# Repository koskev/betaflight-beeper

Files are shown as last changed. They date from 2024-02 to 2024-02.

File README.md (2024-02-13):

# bf-beeper

This is a small beeper board, which is designed to find a lost model aircraft.
It functions pretty much identical to the other commercial beepers.
The main feature is the ability to deactivate the beeper using Betaflight.

Just activate the normal beeper function of Betaflight and pull the battery.
Since the manual beep pattern is unique all other beep sources won't trigger the disarm.

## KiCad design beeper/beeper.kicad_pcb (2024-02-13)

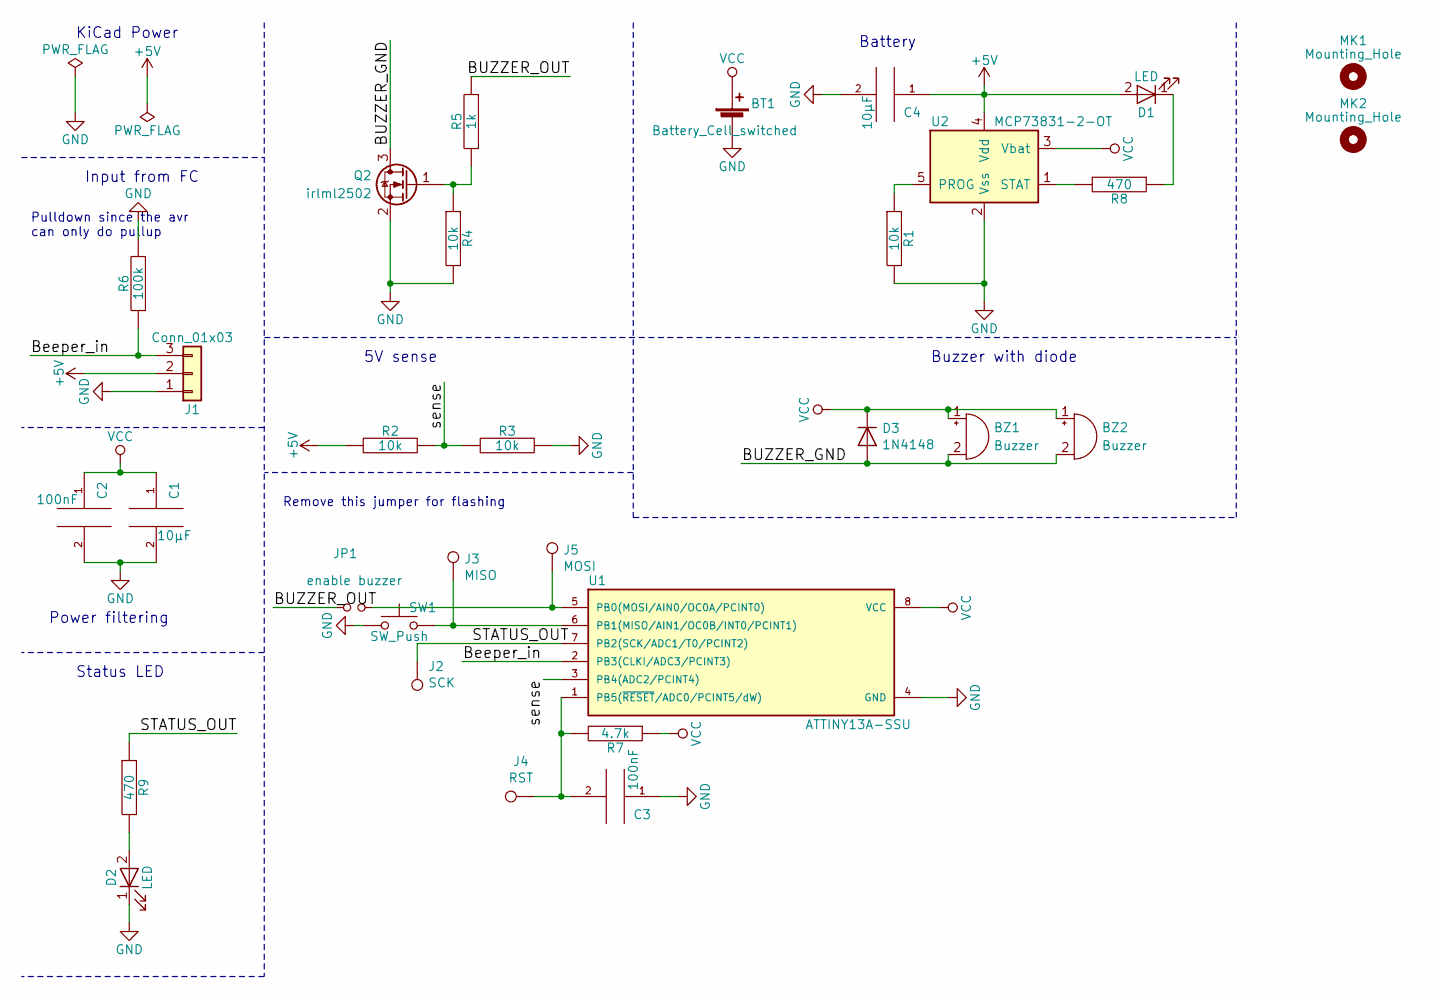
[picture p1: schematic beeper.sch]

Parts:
BT1: Battery_Cell_switched; PinHeader_2x01_P2.00mm_Vertical
BZ1: Buzzer; Buzzer_12x9.5RM7.6_oval3
BZ2: Buzzer; Buzzer_Murata_PKMCS0909E4000-R1
C1, C4: 10µF; C_0805_2012Metric
C2, C3: 100nF; C_0603_1608Metric
D1, D2: LED; LED_0805_2012Metric_Castellated
D3: 1N4148; D_SOD-323
J1: Conn_01x03; PinHeader_1x03_P2.54mm_Vertical
J2: SCK; TestPoint_Pad_D1.0mm
J3: MISO; TestPoint_Pad_D1.0mm
J4: RST; TestPoint_Pad_D1.0mm
J5: MOSI; TestPoint_Pad_D1.0mm
JP1: enable buzzer; SolderJumper-2_P1.3mm_Open_RoundedPad1.0x1.5mm
MK1, MK2: Mounting_Hole; MountingHole_3.2mm_M3
Q2: irlml2502; SOT-23
R1, R2, R3, R4: 10k; R_0805_2012Metric
R5: 1k; R_0805_2012Metric
R6: 100k; R_0805_2012Metric
R7: 4.7k; R_0805_2012Metric
R8, R9: 470; R_0805_2012Metric
SW1: SW_Push; SW_SPST_CK_RS282G05A3
U1: ATTINY13A-SSU; SOIC-8_3.9x4.9mm_P1.27mm
U2: MCP73831-2-OT; SOT-23-5

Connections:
+5V: C4.1, D1.2 (A), J1.2, R2.1, U2.4 (Vdd)
/BUZZER_GND: BZ1.2 (+), BZ2.2 (+), D3.2 (A), Q2.3 (D)
/BUZZER_OUT: JP1.1, R5.2
/Beeper_in: J1.3, R6.1, U1.2 (PB3(CLKI/ADC3/PCINT3))
/STATUS_OUT: J2.1, R9.1, U1.7 (PB2(SCK/ADC1/T0/PCINT2))
/sense: R2.2, R3.1, U1.3 (PB4(ADC2/PCINT4))
GND: BT1.1 (-), C1.2, C2.2, C3.1, C4.2, D2.1 (K), J1.1, Q2.2 (S), R1.2, R3.2, R4.2, R6.2, SW1.1, U1.4 (GND), U2.2 (Vss)
unnamed: C3.2, J4.1, R7.2, U1.1 (PB5(~RESET~/ADC0/PCINT5/dW))
unnamed: D1.1 (K), R8.1
unnamed: D2.2 (A), R9.2
unnamed: J3.1, SW1.2, U1.6 (PB1(MISO/AIN1/OC0B/INT0/PCINT1))
unnamed: J5.1, JP1.2, U1.5 (PB0(MOSI/AIN0/OC0A/PCINT0))
unnamed: Q2.1 (G), R4.1, R5.1
unnamed: R1.1, U2.5 (PROG)
unnamed: R8.2, U2.1 (STAT)
VCC: BT1.2 (+), BZ1.1 (-), BZ2.1 (-), C1.1, C2.1, D3.1 (K), R7.1, U1.8 (VCC), U2.3 (Vbat)

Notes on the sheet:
KiCad Power
Input from FC
Battery
Power filtering
5V sense
Status LED
Buzzer with diode
Pulldown since the avr can only do pullup
Remove this jumper for flashing

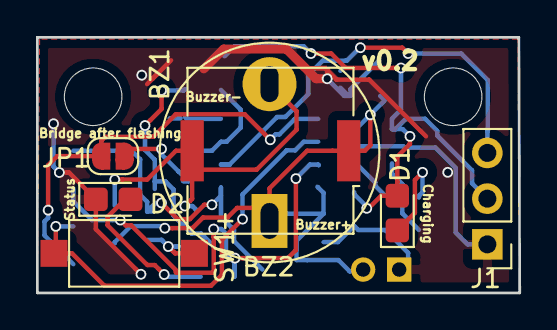
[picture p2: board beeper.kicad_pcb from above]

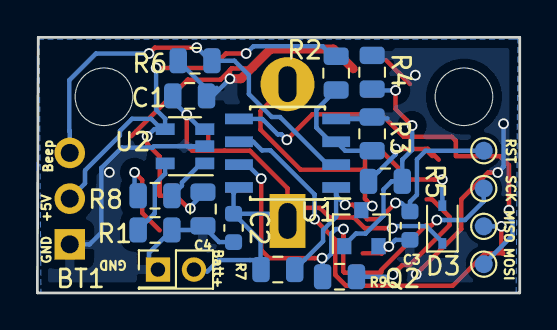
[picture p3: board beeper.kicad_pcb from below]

Board: 2 copper layers, 26.8 x 14.2 mm, 31 parts (22 on the bottom side), 16 nets.

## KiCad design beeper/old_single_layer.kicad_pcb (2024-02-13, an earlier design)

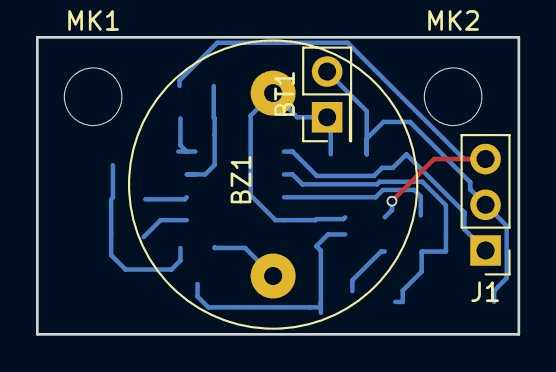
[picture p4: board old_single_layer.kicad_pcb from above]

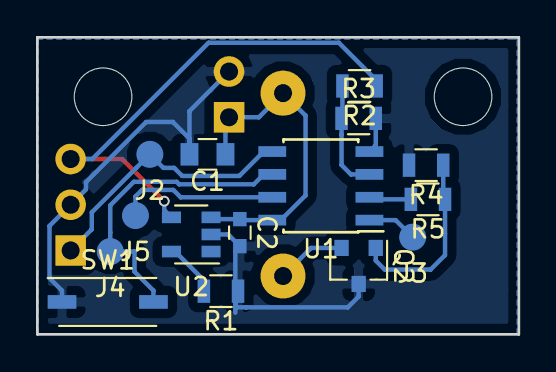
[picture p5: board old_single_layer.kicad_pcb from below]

Board: 2 copper layers, 26.8 x 16.5 mm, 20 parts (15 on the bottom side), 12 nets.

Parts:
BT1: Battery_Cell; Pin_Header_Straight_2x01_Pitch2.54mm
BZ1: Buzzer; BUZZER
C1: 10µF; C_0805
C2: 100nF; C_0603
J1: Conn_01x03; Pin_Header_Straight_1x03_Pitch2.54mm
J2, J3, J4, J5: TEST_1P; Measurement_Point_Round-SMD-Pad_Small
MK1, MK2: Mounting_Hole; MountingHole_3.2mm_M3
Q2: Q_NMOS_DGS; SOT-23
R1, R2, R3, R4, R5: R; R_0805
SW1: SW_Push; SW_DIP_x1_W5.08mm_Slide_Copal_CHS-A
U1: ATTINY13A-SSU; SOIC-8_3.9x4.9mm_Pitch1.27mm
U2: MCP73831-2-OT; SOT-23-5

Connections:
+5V: J1.3, R2.1, U2.4
/Beeper_in: J1.1, J2.1, U1.5
/sense: R2.2, R3.1, U1.3
GND: BT1.2, C1.2, C2.2, J1.2, Q2.3, R1.1, R3.2, R4.2, SW1.1, U1.4, U2.2
unnamed: BZ1.1, Q2.2
unnamed: J3.1, U1.1
unnamed: J4.1, SW1.2, U1.6
unnamed: J5.1, U1.7
unnamed: Q2.1, R4.1, R5.1
unnamed: R1.2, U2.5
unnamed: R5.2, U1.2
VCC: BT1.1, BZ1.2, C1.1, C2.1, U1.8, U2.3

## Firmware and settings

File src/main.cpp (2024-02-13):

/*
 * Copyright (c) 2024 Kevin Köster.
 *
 * This file is part of betaflight-beeper 
 * (see https://github.com/Smeat/betaflight-beeper).
 *
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
 * You should have received a copy of the GNU General Public License
 * along with this program. If not, see <http://www.gnu.org/licenses/>.
 */

#include <avr/io.h>
#include <avr/interrupt.h>
#include <avr/sleep.h>
#include <avr/wdt.h>
#include <avr/power.h>
#include <util/delay.h>

#include <string.h>

// in case we compile as C code. But compiling with g++ saves a few bytes
#ifndef __cplusplus
#define bool uint8_t
#define true 1
#define false 0
#endif

#define STATIC_TEST static

#define SENSE_DDR DDRB
#define SENSE_PORT PORTB
#define SENSE_PIN PB4

#define BEEPER_IN_DDR DDRB
#define BEEPER_IN_PORT PORTB
#define BEEPER_IN_PIN PB3

#define BEEPER_OUT_DDR DDRB
#define BEEPER_OUT_PORT PORTB
#define BEEPER_OUT_PIN PB0

#define BUTTON_DDR DDRB
#define BUTTON_PORT PORTB
#define BUTTON_PIN PB1

#define LED_DDR DDRB
#define LED_PORT PORTB
#define LED_PIN PB2

#define BEEP_PATTERN_SIZE 2
#define BEEP_PATTERN_NUM 2

#define STAGE1_TRIGGER_TIME 15 * 60 * 1000UL
#define STAGE1_SLEEP_CYLCLES 5

#define STAGE2_TRIGGER_TIME 120 * 60 * 1000UL
#define STAGE2_SLEEP_CYLCLES 10

#define internal_to_ms(x) x*16
#define ms_to_internal(x) x/16

#define FREQ_TO_COMPARE_VAL(x) (F_CPU/(2*x)-1)

#define SIGNAL_ACTIVE_LOW

#define BEEP_DELAY_TIME ms_to_internal(60*1000UL)

enum state {
	POWER_OFF,
	CONNECTED,
	DISCONNECTED,
};

// We are starting as disconnected
volatile uint8_t state = DISCONNECTED;
// flag to stop sleep cycle. used to avoid long delays, when recovering the quad
volatile bool stop_sleep = false;
bool turn_off_signal_received = false;

// XXX: this costs so much flash -.-
// disconnect variables
// since we only count in 16ms increments this this is saved as 16ms.
// overflows in 50 days. so plenty
uint32_t total_time = 0;

#define USE_RUNTIME_FREQ_SET

#ifdef USE_RUNTIME_FREQ_SET
uint8_t base_freq = 21;
#else
#define base_freq 21
#endif


// Alternating on/off times
// 2^(i+1) = cylces
// time = cycles/2^(10) * 16
// or use WDTO_ defines
// -1 = end of cycle

typedef struct pattern_s{
	uint8_t on_time;
	int8_t freq_offset;
	uint8_t off_time;
	uint8_t repeat;
} pattern_t;

// max vol = 21
pattern_t beep_pattern[BEEP_PATTERN_NUM][BEEP_PATTERN_SIZE] = {{{WDTO_250MS, 0, WDTO_250MS, 4}, {WDTO_250MS, 0, WDTO_250MS, 0}},
																{{WDTO_1S, 0, WDTO_1S, 4}, {WDTO_250MS, 0, WDTO_250MS, 2}}};
uint8_t current_pattern = 0;

// saves space -.-
STATIC_TEST inline uint32_t convert_wdto_to_16ms(uint8_t wdto_time){
	// 2^x = 16ms
	return (1UL << (wdto_time));
}

STATIC_TEST inline void disable_pin_int(){
	GIMSK &= ~(1 << PCIE);
}

STATIC_TEST bool is_turn_off_condition_set(){
	return (total_time > ms_to_internal(2000) && total_time < ms_to_internal(8000));
}

STATIC_TEST inline void enable_pin_int(){
	GIMSK |= (1 << PCIE);
}

STATIC_TEST bool is_beeper_input_set(){
#ifdef SIGNAL_ACTIVE_LOW
	return !(PINB & (1 << BEEPER_IN_PIN));
#else
	return PINB & (1 << BEEPER_IN_PIN);
#endif
}

STATIC_TEST inline bool is_button_pressed(){
	// button is active low
	return !(PINB & (1 << BUTTON_PIN));
}

STATIC_TEST inline void set_watchdog(uint8_t time){
	wdt_reset();
	WDTCR = (1 << WDCE) | (1 << WDTIE) | (time & 0x08 ? (1 << WDP3) : 0x00) | (time & 0x07);
}

STATIC_TEST inline void led_enable(){
	LED_PORT |= (1 << LED_PIN);
}

STATIC_TEST inline void led_disable() {
	LED_PORT &= ~(1 << LED_PIN);
}

STATIC_TEST void sleep(uint8_t time){
	// TODO: disable stuff?

	//enable wdt
	set_watchdog(time);
	// Entering sleep (this sets and clears the flag)
	sleep_mode();
	total_time += convert_wdto_to_16ms(time);
	// TODO: do we need this?
	//wdt_disable();
}

STATIC_TEST bool is_button_long_pressed(){
	if(is_button_pressed()){
		led_enable();
		disable_pin_int();
		sleep(WDTO_2S);
		enable_pin_int();
		led_disable();
	}
	return is_button_pressed();
}

// never tested
#ifdef ENABLE_PATTERN_EDIT
STATIC_TEST inline void record_pattern(uint8_t num){
	bool initial_state = is_beeper_input_set();
	for(int i = 0; i < BEEP_PATTERN_SIZE; ++i){
		// sleep for all possible times until the state changes
		for(uint8_t j = 0; j < WDTO_8S+1; ++j){
			sleep(j);
			// end sequence if button was pressed
			if(is_button_pressed()){
				//eeprom_update_byte((uint8_t*)&beep_pattern[num][i],WDTO_8S + 1);
				beep_pattern[num][i] = WDTO_8S + 1;
				break;
			}
			else if(is_beeper_input_set() != initial_state){
				// state changed or max time, save
				//eeprom_update_byte((uint8_t*)&beep_pattern[num][i],j);
				beep_pattern[num][i] = j;
				break;
			}
		}
	}
}
#endif

STATIC_TEST void sleep_cycles(uint8_t time, uint8_t cycles){
	stop_sleep = false;
	while(cycles && !stop_sleep){
		sleep(time);
		--cycles;
	}
}

STATIC_TEST inline bool is_connected(){
	return PINB & (1 << SENSE_PIN);
}

// Splitting them saves a few bytes
STATIC_TEST void beep_enable(uint8_t freq){
	// set sleep mode to idle to enable pwm
	set_sleep_mode(SLEEP_MODE_IDLE);
	TCNT0 = 254;
	//BEEPER_OUT_PORT |= (1 << BEEPER_OUT_PIN);
	OCR0A = freq;
	// non-inverting mode and ctc
	TCCR0A |= (1 << COM0A0);
}

STATIC_TEST inline void beep_disable() {
	TCCR0A &= ~(1 << COM0A0);
	set_sleep_mode(SLEEP_MODE_PWR_DOWN);
	//OCR0A = 0;
	//BEEPER_OUT_PORT &= ~(1 << BEEPER_OUT_PIN);
	//TCNT0 = 0;
}

/**
 * "Totally" power off the µC. Can only be waked by button press or beep line. Used when user requests power off manually
 */
STATIC_TEST inline void power_off() {
	// Play confirm pattern
	beep_enable(15);
	sleep(WDTO_120MS);
	beep_disable();
	sleep(WDTO_120MS);
	beep_enable(15);
	sleep(WDTO_120MS);

	// disable beeper
	beep_disable();
	led_disable();
	// disable watchdog
	wdt_disable();
	// enter sleep
	// should be around 0.5µA. So a fet to power itself off would be useless
	// but consumes more space
	sleep_mode();
}

STATIC_TEST inline void on_connect(){
	total_time = 0; // reset time on connect event
}

STATIC_TEST void connected_action(){
	static uint8_t signal_time[4] = {0,0,0,0};
	static bool last_beep_status = false;

	// just beep if input signal
	if(is_beeper_input_set()) {
		beep_enable(base_freq);
	}
	else {
		beep_disable();
	}

	if(is_turn_off_condition_set() || is_beeper_input_set() || turn_off_signal_received) {
		led_enable();
	}
	else {
		led_disable();
	}

	// shift on overflow or signal change
	if(last_beep_status != is_beeper_input_set() || signal_time[0] == 254){
		signal_time[3] = signal_time[2];
		signal_time[2] = signal_time[1];
		signal_time[1] = signal_time[0];
		signal_time[0] = 0;
		last_beep_status = is_beeper_input_set();
	}

	// Turn off if betaflight sends continous beeps 100ms on 100ms off
	turn_off_signal_received = signal_time[3] > ms_to_internal(70) && signal_time[3] < ms_to_internal(130) &&
			signal_time[2] > ms_to_internal(70) && signal_time[2] < ms_to_internal(130) &&
			signal_time[1] > ms_to_internal(70) && signal_time[1] < ms_to_internal(130);
			//&&	last_beep_status;

#ifdef USE_RUNTIME_FREQ_SET
	if(is_button_pressed()){
		if(is_button_long_pressed()){
			--base_freq;
		} else {
			++base_freq;
		}
	}
#endif

	// sleep a little bit to keep the timer running. avoids using another timer
	sleep(WDTO_15MS);

#ifdef ENABLE_PATTERN_EDIT
	static uint8_t edit_num = 0;
	// this is the number of loops 1=16ms. so overflows after about 4 sec
	static uint8_t edit_time = 0;
	// TODO: use loop counter to detect button press length
	if(is_button_pressed()){
		edit_time = 0;
		++edit_num;
		if(edit_num > BEEP_PATTERN_NUM){
			edit_num = 1;
		}
		disable_pin_int();
		// Beep edit_num times to confirm position
		for(int i = 1; i < edit_num+1; ++i){
			beep_enable();
			sleep(WDTO_120MS);
			beep_disable();
			sleep(WDTO_120MS);
		}
		// TODO: determine sleep time
		sleep(WDTO_500MS);
		enable_pin_int();
	}
	// button was pressed to enable edit and first signal is there
	if(edit_num != 0){
		if(is_beeper_input_set()){
			record_pattern(edit_num);
			goto set_pattern;
		}
		// Timeout in 254*15ms = 3810ms
		if(edit_time == 254){
			set_pattern:
			current_pattern = edit_num;
			edit_num = 0;
		}
	}
	++edit_time;
#endif
	++signal_time[0];
}

STATIC_TEST inline void on_disconnect(){
	// disable beeper in case it was beeping
	beep_disable();
	led_disable();

	if( is_turn_off_condition_set() || turn_off_signal_received){
		// power off, if bepper is set, while pulling the power <- not a good idea
		// or total power on time is less than 8 seconds (this might impose problems, when a battery is ejected)
		// or power on time is > 2sec and <8 sec
		state = POWER_OFF;
	}
	// power down all unneeded features?

	// reset time on disconnect, as we don't need a separate variable
	total_time = 0;
}

STATIC_TEST inline void disconnected_action(){
	// wait until BEEP_DELAY_TIME to start beeping
	if(total_time > BEEP_DELAY_TIME) {
		led_disable();
		for(uint8_t i = 0; i < BEEP_PATTERN_SIZE; ++i){
			//uint8_t pattern = eeprom_read_byte((const uint8_t*)&beep_pattern[current_pattern][i]);
			pattern_t pattern = beep_pattern[current_pattern][i];
			// repeat pattern j times
			for(uint8_t j = 0; j < pattern.repeat; ++j){
				// Beep enable part
				beep_enable(base_freq + pattern.freq_offset);
				// sleep instead of simple delay
				sleep(pattern.on_time);

				// off time part
				beep_disable();
				sleep(pattern.off_time);
				// in case we are pressing the button while beeping
				if(stop_sleep){
					stop_sleep = false;
					goto disconnected_check_button;
				}
			}
		}

		// cycle through all patterns
		if(++current_pattern >= BEEP_PATTERN_NUM){
			current_pattern = 0;
		}
	} else {
		// Very low noise beep to indicate armed status
		beep_enable(5);
		sleep(WDTO_15MS);
		beep_disable();
	}

	// increase delay when beeping for a longer time
	if(total_time < STAGE1_TRIGGER_TIME){
		// STAGE 0
		sleep_cycles(WDTO_2S, 1);
	}
	else if(total_time < STAGE2_TRIGGER_TIME){
		// stage 1
		sleep_cycles(WDTO_8S, STAGE1_SLEEP_CYLCLES);
	}
	else {
		// stage 2
		sleep_cycles(WDTO_8S, STAGE2_SLEEP_CYLCLES);
	}

disconnected_check_button:
	if(is_button_long_pressed()){
		// Button still pressed after 2 sec. so shutdown
		// if button is not pressed after 4 sec we are pretty sure it is a human interaction
		sleep(WDTO_2S);
		if(!is_button_pressed()){
			state = POWER_OFF;
		}
	}

}

/**
 * Possible state transitions
 *
 * power off -> connected <->  disconnected -> power off
 */
STATIC_TEST inline void check_status(){
	if(is_connected()){
		// triggered on power on or disconnected -> connected
		if(state != CONNECTED){
			state = CONNECTED;
			on_connect();
		}
	}
	else {
		if(state == CONNECTED){
			state = DISCONNECTED;
			on_disconnect();
		}
	}

	if(state == CONNECTED){
		connected_action();
	}
	else if(state == DISCONNECTED){
		disconnected_action();
	}
	else {
		power_off();
	}

}

ISR(PCINT0_vect){
	// Wakeup from power down
	// no need to do anything
	// Set stop sleep flag for sleep_cycle
	stop_sleep = true;
}

ISR(WDT_vect){
	//TODO: do we need to disable the watchdog?
	MCUSR &= ~(1 << WDRF);
	WDTCR |= (1 << WDTIE);
}

int main(){
	DDRB = 0; // all input
	PORTB = 0xFF; // enable all pullups (saves power)
	
	// enable LED out
	LED_DDR |= (1 << LED_PIN);

	// enable beeper output
	BEEPER_OUT_DDR |= (1 << BEEPER_OUT_PIN);
	BEEPER_OUT_PORT &= ~(1 << BEEPER_OUT_PIN);

	TCCR0A = (1 << WGM01);

	// no pwm prescaler
	TCCR0B = (1 << CS00);

	// pulldown not installed and signal inverted
#ifndef SIGNAL_ACTIVE_LOW
	BEEPER_IN_PORT &= ~(1 << BEEPER_IN_PIN);
#endif

	SENSE_PORT &= ~(1 << SENSE_PIN);

	// Enable interrupt on any change on int0 and pcint
	enable_pin_int();
	// enable int on beeper_in, button and sense
	PCMSK |= (1 << PCINT1) | (1 << PCINT4);

	// enable int0. not needed for now, since we are using pcint
	////MCUCR |= (1 << ISC01) | (1 << ISC00);

	WDTCR = (1<<WDCE);
	//Enable watchdog for int only
	WDTCR = (1<<WDTIE);
	
	// set sleep to power down
	set_sleep_mode(SLEEP_MODE_PWR_DOWN);

	// Disable adc
	ADCSRA &= ~(1 << ADEN);
	ACSR |= (1 << ACD);
	// disable timer0 and adc (doesn't do anything on attiny13)
	power_all_disable();

	sei();

	while(42){
		check_status();
	}
}

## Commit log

2024-02-13 First version.
    [beeper.kicad_pcb, beeper.sch, beeper_mcp.sch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]
2024-02-13 Version 2.
    [beeper-2019-03-09-14-32-43.sch, beeper.kicad_pcb, beeper.sch]
2024-02-13 PCB v0.2
    [beeper.kicad_pcb, beeper.sch]
2024-02-13 PCB v0.2 final
    [beeper-B_Cu.gbr, beeper-B_Mask.gbr, beeper-B_Paste.gbr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]
2024-02-13 Working firmware with passive buzzer.
    [main.cpp]
2024-02-13 Final v0.2 (ordered)
    [beeper.kicad_pcb, beeper.sch]
2024-02-13 Update pcb info

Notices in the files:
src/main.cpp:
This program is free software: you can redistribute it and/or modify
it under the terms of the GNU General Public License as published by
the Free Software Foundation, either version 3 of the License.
